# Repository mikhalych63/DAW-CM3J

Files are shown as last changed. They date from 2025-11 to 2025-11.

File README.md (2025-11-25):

Audio Processor and 8ch Amplifier with CamillaDSP on RADXA CM3J board

Это мой крайний РАБОТАЮЩИЙ проект автомобильного процессорного усилителя 
Проект состоит из проекта KiCAD, проекта корпуса FreeCAD и набора софта для запуска в работу.

Железо: 
Вычислитель - одноплатный компьютер Radxa CM3J в формфакторе Raspberry Pi CM4 на чипе RK3568, 2gB RAM, 8gB EMMC, WiFi. 
Усилитель - две микросхемы TAS6424-Q1, 4-хканальные усилители со входом I2S, суммарная мощность 8х50 Вт. 
Аналоговый вход - АЦП PCM1808, аналоговый выход - ЦАП PCM5102A. Аппаратоно-программный энкодер для регулировки громкости. 
Блок питания - преобразователь с бортового автомобильного в 25В однополярного напряжения со стаблизацией. 
Все помещено корпус из алюминия.

Софт: ОС Armbian, модифицировано дерево устройств. 
Обработка заука - СamillaDSP, плеер - mpd, приемник DLNA - upmpdcli, приемник USB - g_audio (виртуальный гаджет, частота дискретизации до 192 КГц), 
набор скриптов для инициализации усилителей, управления питанием, энкодером и т.д.

Проект выкладывается как есть. Любой желающий может его скачать, заказать платы, спаять и запустить в работу.

С документацией плохо, нужно время.

Небольшое описание проекта на Драйве: https://www.drive2.ru/b/716015167221021455/

Группа для обсуждения: https://t.me/DigitalAudioWare

Виктор Хомченко https://t.me/mikhalych24 Красноярск 2025г.

EN:

Audio processor and 8-channel amplifier with CamillaDSP on a RADXA CM3J board

This is my last WORKING automotive processor amplifier project. 
The project consists of a project in KiCad, a case project in FreeCAD, and a set of startup software.

Hardware: Radxa CM3J single—board computer in Raspberry Pi CM4 form factor on RK3568 chip, 2 GB RAM, 8 GB EMMC, WiFi. 
Amplifier — two TAS6424-Q1 chips, 4-channel amplifiers with I2S input, total power 8x50 watts. 
The analog input is the PCM1808 ADC, the analog output is the PCM5102A DAC. 
A hardware-software encoder for volume control. 
The power supply unit is a converter of on—board automotive voltage to a unipolar voltage of 25 V with stabilization. 
Everything is housed in an aluminum case.

Software: Armbian OS, modified device tree. Sound processing — CamillaDSP, MPD player, DLNA receiver — upmpdcli, 
USB receiver — g_audio (virtual gadget, sampling rate up to 192 kHz), 
a set of scripts for initializing amplifiers, power management, encoder, etc.

The project is laid out as it is. Anyone can download it, order the boards, solder it and put it into operation.

There are problems with the documentation, it takes time.

A brief description of the project on Drive2: https://www.drive2.ru/b/716015167221021455/

The discussion group: https://t.me/DigitalAudioWare

Viktor Khomchenko https://t.me/mikhalych24 Krasnoyarsk, 2025

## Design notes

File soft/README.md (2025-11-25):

Содержимое каталогов 
/etc
/opt/bin
/usr/local
скопировать в соответствующие каталоги в системе

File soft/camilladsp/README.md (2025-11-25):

Установщик CamillaDSP

Возможно неактуально, смотрите

https://github.com/HEnquist/camilladsp

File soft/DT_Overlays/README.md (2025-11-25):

Эти оверлеи подходят только к моей плате и к плате Radxa CM3J, т.к. использованы конкретные выводы конкретного одноплатника.
Для включения оверлея ввести команду от пользователя root:

armbian-add-overlay оверлей.dts

и перезагрузать систему.

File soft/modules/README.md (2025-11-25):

Сначала установить kernel headers:

sudo armbian-config -> software -> headers install

Затем модули нужно скомпилировать и установить в систему командами:
make
sudo make install

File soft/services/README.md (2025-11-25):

Скопировать все сервисы в каталог /lib/systemd/system и разрешить запуск:

sudo systemctl enable сервис.service

Запустить:

sudo systemctl start сервис.service

Проверить: 

sudo systemctl status сервис.service

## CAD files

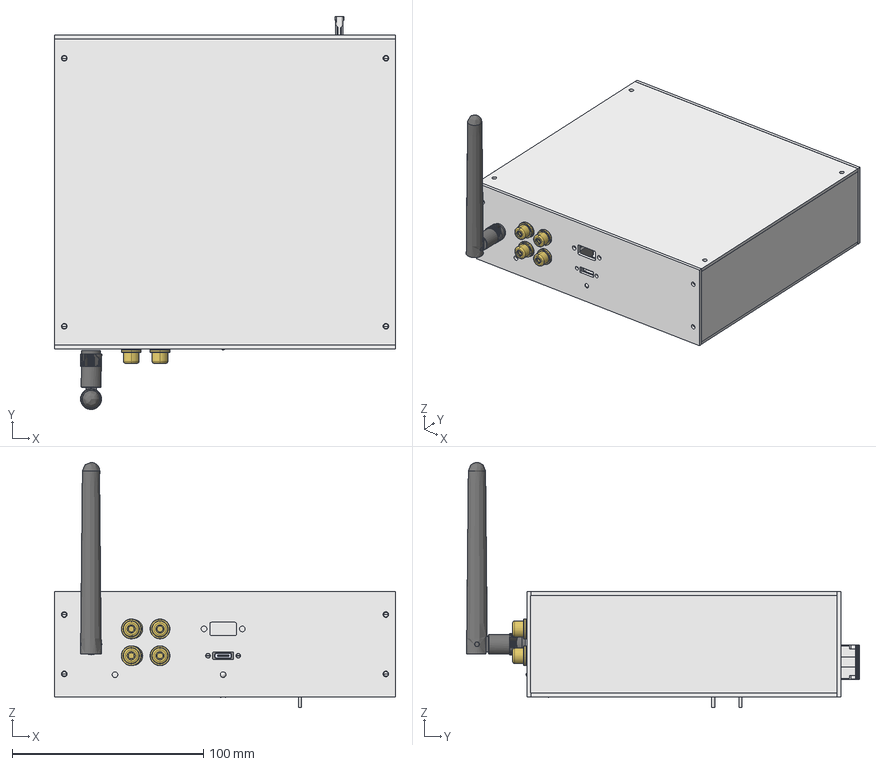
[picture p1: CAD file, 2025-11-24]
Enlosure/enclosure.FCStd
178.3 x 205.3 x 128.1 mm
Bottom
R_0603_1608Metric x 38
Tube001
Tube
Нога2
Нога1
Куб
fuse_automotive_10a001
fuse_automotive_10a
C_0603_1608Metric x 89
C_1206_3216Metric x 12
CAD_SPM5020-LR x 16
DIP-4_W7.62mm x 4
D_SMC x 5
2300HT-100-V-RC
ETD 44
R_Axial_DIN0204_L36mm_D16mm_P508mm_Vertical x 4
LED_0603_1608Metric x 4
D_SMA x 8
CP_EIA_3216_18_Kemet_A x 2
CP_Radial_D100mm_P500mm x 3
R_1206_3216Metric x 2
L_Axial_L26.0mm_D9.0mm_P5.08mm_Vertical_Fastron_77A
CP_Elec_8x10 x 2
CQ assembly x 3
CP_Radial_D140mm_P500mm x 2
SOT_23
SOIC_16_39x99mm_P127mm
SW_Tactile_SPST_Angled_PTS645Vx58-2LFS
D_DO-34_SOD68_P7.62mm_Horizontal
PinHeader_1x03_P254mm_Vertical
LED_D3.0mm_Horizontal_O6.35mm_Z10.0mm
SSOP_56_75x185mm_P0635mm x 2
TO-220-3_Horizontal_TabUp x 4
DAW-Pro4_PCB
Front
Back
Right
Left
Top
TYPE-C-14-vertical_H-10mm1^TYPE-C-14-vertical_H-10mm(2)_TYPE-C-14-vertical_H-10mm
TYPE-C-14-vertical_H-10mm2^TYPE-C-14-vertical_H-10mm(2)_TYPE-C-14-vertical_H-10mm
TYPE-C-14-vertical_H-10mm3^TYPE-C-14-vertical_H-10mm(2)_TYPE-C-14-vertical_H-10mm
USB C female wall
USB C female PCB
ant
conn_body
SMA_threads
socket
RCA
RCA001
RCA002
RCA003
C_0805_2012Metric x 5
JST_B3B_XH_A x 2
TSSOP_14_44x5mm_P065mm
Potentiometer_Bourns_3314G_Vertical x 2
TSSOP_20_44x65mm_P065mm
analog_input_PCB

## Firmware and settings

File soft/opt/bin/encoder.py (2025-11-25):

import evdev
import sys
import os
import time
import yaml
import glob
from camilladsp import CamillaClient

cdsp = CamillaClient("127.0.0.1",1234)
cdsp.connect()

encoder=evdev.InputDevice('/dev/input/event0')
encoder.grab()

active = cdsp.config.file_path()
configdir = active.split('camilladsp/configs/')[0] + 'camilladsp/configs/'

def main():

  for event in encoder.read_loop():
       config = glob.glob(configdir + '_*')
       cdspvolume = cdsp.volume.main()
       cdspmute = cdsp.mute.main()
       cdspvolumeold = cdspvolume
       if event.type == evdev.ecodes.EV_REL:
            attrib = evdev.categorize(event)
            if str(attrib.event.value) == '-1':
                if cdspvolume - 1 >= -99: #change to cdspvolume - 0.5 if you want 0.5 dB increments
                    cdsp.volume.set_main(cdspvolume - 1) # change to cdspvolume - 0.5 if you want 0.5 dB increments
                    cdspvolume = cdsp.volume.main()
                else:
                    cdsp.volume.set_main(-99)
                    cdspvolume = cdsp.volume.main()

            elif str(attrib.event.value) == '1':
                if cdspvolume + 1 < 0: #change to cdspvolume + 0.5 if you want 0.5 dB increments
                     cdsp.volume.set_main(cdspvolume + 1) #change to cdspvolume + 0.5 if you want 0.5 dB increments
                     cdspvolume = cdsp.volume.main()
                else:
                     cdsp.volume.set_main(0)
                     cdspvolume = cdsp.volume.main()


if __name__ == '__main__':

  try:
    main()
  except KeyboardInterrupt:
    pass

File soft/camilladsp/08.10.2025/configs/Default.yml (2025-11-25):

description: "\u0412\u0445\u043E\u0434 \u043E\u0442 \u0432\u0441\u0442\u0440\u043E\
  \u0435\u043D\u043D\u043E\u0433\u043E \u043F\u043B\u0435\u0435\u0440\u0430 \u0438\
  \u043B\u0438 Bluetooth\n\u041F\u043E\u043A\u0430\u043D\u0430\u043B\u044C\u043D\u044B\
  \u0439 \u0432\u044B\u0445\u043E\u0434 \u043D\u0430 4 \u043F\u043E\u043B\u043E\u0441\
  \u044B\nFIR \u043A\u0440\u043E\u0441\u0441\u043E\u0432\u0435\u0440"
devices:
  adjust_period: null
  capture:
    channels: 2
    device: hw:CARD=Loopback,DEV=1
    format: S24LE
    type: Alsa
  capture_samplerate: 96000
  chunksize: 4096
  enable_rate_adjust: true
  playback:
    channels: 8
    device: hw:CARD=i2s8ch0,DEV=0
    format: S32LE
    type: Alsa
  queuelimit: null
  rate_measure_interval: null
  resampler:
    profile: Balanced
    type: AsyncSinc
  samplerate: 96000
  silence_threshold: null
  silence_timeout: null
  stop_on_rate_change: null
  target_level: null
  volume_ramp_time: null
filters:
  Bass:
    description: null
    parameters:
      freq: 85
      gain: 0
      slope: 0.9
      type: Lowshelf
    type: Biquad
  DRC-Left:
    description: null
    parameters:
      channel: 0
      filename: ../coeffs/LeftSpeaker48000NORMAL.wav
      type: Wav
    type: Conv
  DRC-Right:
    description: null
    parameters:
      channel: 0
      filename: ../coeffs/RightSpeaker48000NORMAL.wav
      type: Wav
    type: Conv
  Delay0:
    description: null
    parameters:
      delay: 0
      subsample: false
      unit: ms
    type: Delay
  Delay1:
    description: null
    parameters:
      delay: 0
      subsample: false
      unit: ms
    type: Delay
  Delay2:
    description: null
    parameters:
      delay: 0
      subsample: false
      unit: ms
    type: Delay
  Delay3:
    description: null
    parameters:
      delay: 0
      subsample: false
      unit: ms
    type: Delay
  Delay4:
    description: null
    parameters:
      delay: 0
      subsample: false
      unit: ms
    type: Delay
  Delay5:
    description: null
    parameters:
      delay: 0
      subsample: false
      unit: ms
    type: Delay
  Delay6:
    description: null
    parameters:
      delay: 0
      subsample: false
      unit: ms
    type: Delay
  Delay7:
    description: null
    parameters:
      delay: 0
      subsample: false
      unit: ms
    type: Delay
  Gain0:
    description: null
    parameters:
      gain: 0
      inverted: false
      mute: false
      scale: dB
    type: Gain
  Gain1:
    description: null
    parameters:
      gain: 0
      inverted: false
      mute: false
      scale: dB
    type: Gain
  Gain2:
    description: null
    parameters:
      gain: -3
      inverted: false
      mute: false
      scale: dB
    type: Gain
  Gain3:
    description: null
    parameters:
      gain: -3
      inverted: false
      mute: false
      scale: dB
    type: Gain
  Gain4:
    description: null
    parameters:
      gain: 0
      inverted: false
      mute: false
      scale: dB
    type: Gain
  Gain5:
    description: null
    parameters:
      gain: 0
      inverted: false
      mute: false
      scale: dB
    type: Gain
  Gain6:
    description: null
    parameters:
      gain: 0
      inverted: false
      mute: false
      scale: dB
    type: Gain
  Gain7:
    description: null
    parameters:
      gain: 0
      inverted: false
      mute: false
      scale: dB
    type: Gain
  GainInL:
    description: null
    parameters:
      gain: 0
      inverted: false
      mute: false
      scale: dB
    type: Gain
  GainInR:
    description: null
    parameters:
      gain: 0
      inverted: false
      mute: false
      scale: dB
    type: Gain
  High:
    description: null
    parameters:
      filename: ../coeffs/high4500.txt
      format: TEXT
      read_bytes_lines: 0
      skip_bytes_lines: 0
      type: Raw
    type: Conv
  Low:
    description: null
    parameters:
      filename: ../coeffs/low350.txt
      format: TEXT
      read_bytes_lines: 0
      skip_bytes_lines: 0
      type: Raw
    type: Conv
  Mid:
    description: null
    parameters:
      filename: ../coeffs/mid350-4500.txt
      format: TEXT
      read_bytes_lines: 0
      skip_bytes_lines: 0
      type: Raw
    type: Conv
  Sub:
    description: null
    parameters:
      filename: ../coeffs/sub.txt
      format: TEXT
      read_bytes_lines: 0
      skip_bytes_lines: 0
      type: Raw
    type: Conv
  Treble:
    description: null
    parameters:
      freq: 6500
      gain: 0
      slope: 0.7
      type: Lowshelf
    type: Biquad
mixers:
  Main Mixer 1:
    channels:
      in: 2
      out: 8
    description: null
    mapping:
    - dest: 0
      mute: false
      sources:
      - channel: 0
        gain: 0
        inverted: false
        mute: false
        scale: dB
    - dest: 1
      mute: false
      sources:
      - channel: 1
        gain: 0
        inverted: false
        mute: false
        scale: dB
    - dest: 2
      mute: false
      sources:
      - channel: 0
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

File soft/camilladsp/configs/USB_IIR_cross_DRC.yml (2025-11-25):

description: "\u0412\u0445\u043E\u0434 USB\n\u041F\u043E\u043A\u0430\u043D\u0430\u043B\
  \u044C\u043D\u044B\u0439 \u0432\u044B\u0445\u043E\u0434 \u043D\u0430 4 \u043F\u043E\
  \u043B\u043E\u0441\u044B\nIIR \u043A\u0440\u043E\u0441\u0441\u043E\u0432\u0435\u0440\
  \ + \u0430\u0432\u0442\u043E\u043C\u0430\u0442\u0438\u0447\u0435\u0441\u043A\u0430\
  \u044F \u044D\u043A\u0432\u0430\u043B\u0438\u0437\u0430\u0446\u0438\u044F (DRC)"
devices:
  adjust_period: null
  capture:
    channels: 2
    device: plughw:CARD=UAC2Gadget,DEV=0
    format: S24LE
    type: Alsa
  capture_samplerate: 96000
  chunksize: 4096
  enable_rate_adjust: null
  playback:
    channels: 8
    device: hw:i2s8ch0,0,0
    format: S32LE
    type: Alsa
  queuelimit: null
  rate_measure_interval: null
  resampler:
    profile: Balanced
    type: AsyncSinc
  samplerate: 96000
  silence_threshold: null
  silence_timeout: null
  stop_on_rate_change: null
  target_level: null
  volume_ramp_time: null
filters:
  DRC_Left:
    description: null
    parameters:
      channel: 0
      filename: ../coeffs/LeftSpeaker48000NORMAL.wav
      type: Wav
    type: Conv
  DRC_Right:
    description: null
    parameters:
      channel: 0
      filename: ../coeffs/RightSpeaker48000NORMAL.wav
      type: Wav
    type: Conv
  High:
    description: null
    parameters:
      freq: 4000
      order: 2
      type: ButterworthHighpass
    type: BiquadCombo
  Mid-High:
    description: null
    parameters:
      freq: 4000
      order: 2
      type: ButterworthLowpass
    type: BiquadCombo
  Mid-Low:
    description: null
    parameters:
      freq: 350
      order: 2
      type: ButterworthHighpass
    type: BiquadCombo
  Sub:
    description: null
    parameters:
      freq: 80
      order: 4
      type: ButterworthLowpass
    type: BiquadCombo
  Sub-Woof:
    description: null
    parameters:
      freq: 80
      order: 2
      type: ButterworthHighpass
    type: BiquadCombo
  Woof-Mid:
    description: null
    parameters:
      freq: 350
      order: 2
      type: ButterworthLowpass
    type: BiquadCombo
mixers:
  Crossover:
    channels:
      in: 2
      out: 8
    description: null
    mapping:
    - dest: 0
      mute: false
      sources:
      - channel: 0
        gain: 0
        inverted: false
        mute: false
        scale: dB
    - dest: 1
      mute: false
      sources:
      - channel: 1
        gain: 0
        inverted: false
        mute: false
        scale: dB
    - dest: 2
      mute: false
      sources:
      - channel: 0
        gain: 0
        inverted: false
        mute: false
        scale: dB
    - dest: 3
      mute: false
      sources:
      - channel: 1
        gain: 0
        inverted: false
        mute: false
        scale: dB
    - dest: 4
      mute: false
      sources:
      - channel: 0
        gain: 0
        inverted: false
        mute: false
        scale: dB
    - dest: 5
      mute: false
      sources:
      - channel: 1
        gain: 0
        inverted: false
        mute: false
        scale: dB
    - dest: 6
      mute: false
      sources:
      - channel: 0
        gain: 0
        inverted: false
        mute: false
        scale: dB
    - dest: 7
      mute: false
      sources:
      - channel: 1
        gain: 0
        inverted: false
        mute: false
        scale: dB
pipeline:
- bypassed: null
  channel: 0
  description: null
  names:
  - DRC_Left
  type: Filter
- bypassed: null
  channel: 1
  description: null
  names:
  - DRC_Right
  type: Filter
- bypassed: null
  description: null
  name: Crossover
  type: Mixer
- bypassed: null
  channel: 0
  description: null
  names:
  - High
  type: Filter
- bypassed: null
  channel: 1
  description: null
  names:
  - High
  type: Filter
- bypassed: null
  channel: 2
  description: null
  names:
  - Mid-High
  - Mid-Low
  type: Filter
- bypassed: null
  channel: 3
  description: null
  names:
  - Mid-High
  - Mid-Low
  type: Filter
- bypassed: null
  channel: 4
  description: null
  names:
  - Woof-Mid
  - Sub-Woof
  type: Filter
- bypassed: null
  channel: 5
  description: null
  names:
  - Woof-Mid
  - Sub-Woof
  type: Filter
- bypassed: null
  channel: 6
  description: null
  names:
  - Sub
  type: Filter
- bypassed: null
  channel: 7
  description: null
  names:
  - Sub
  type: Filter
processors: {}
title: null

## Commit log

2025-11-24 Начало
    [enclosure.FCStd]
2025-11-25 Софт
2025-11-25 Исправил опечатку
2025-11-25 Добавил группу
